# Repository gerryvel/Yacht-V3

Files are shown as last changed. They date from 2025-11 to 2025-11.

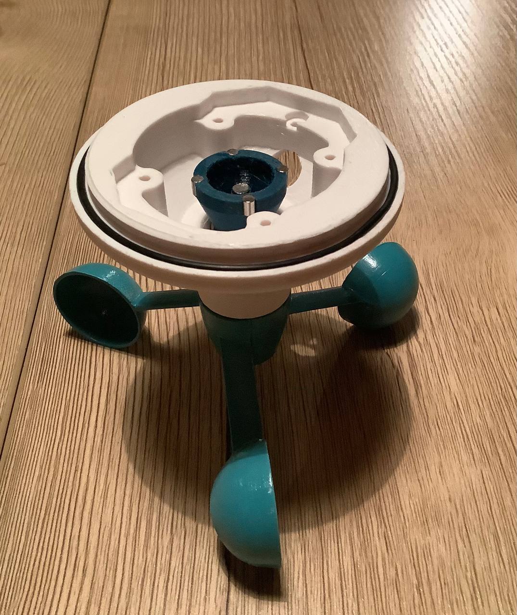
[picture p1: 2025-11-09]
Bilder/photo_2025-11-09_20-17-30.jpg

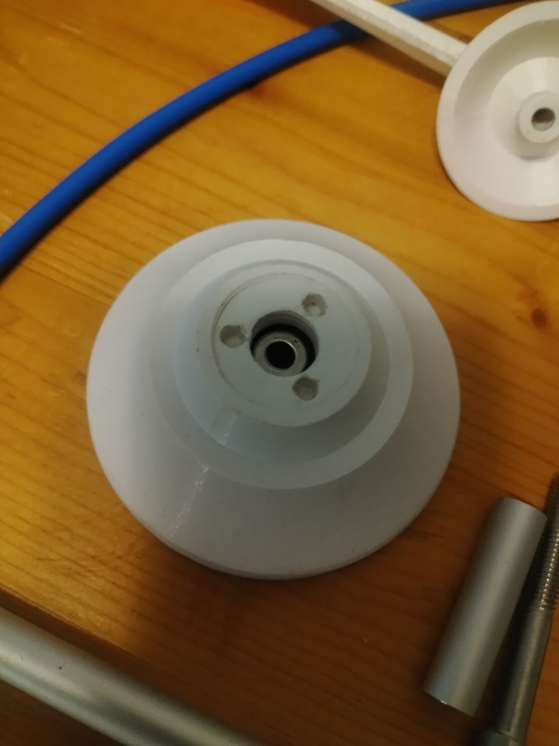
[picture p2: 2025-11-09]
Bilder/photo_2025-11-05_21-48-21.jpg

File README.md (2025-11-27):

# Yachta V3





## Description

This repository describes the installation of the "Yachta V3" wind sensor.

## Based on the work of
 
The Yachta V3 is the Windsensor "Yachta" [@norbert-walter](https://github.com/norbert-walter/Windsensor_Yachta) and the modification from a french user in the www.segeln-forum.de .
You can use the following threads (in German):
- https://www.segeln-forum.de/thread/67401-windsensor-diy/
- https://www.segeln-forum.de/thread/83726-windsensor-yachta-probleml%C3%B6sungen/

This project is part of [OpenBoatProject](https://open-boat-projects.org/)

## Sensor Modul

The PCB is the same as Yachta V2.

## Hardware




## Partlist:

### 1 Print parts
 - 1.1  Windfahne
 - 1.2  Gewindering Lager Windfahne
 - 1.3  Gehäuse-Oberteil
 - 1.4  Gehäuse-Unterteil
 - 1.5  Windlöffel 3x
 - 1.6  Löffelhalter
 - 1.7  Abstandsstück (zwischen Löffellager)
 - 1.8  Magnethalter
 - 1.9  Halterbasis
### 2 Bearings
 - 2.1  Lager 2x 625 (5x16x5 mm)
 - 2.2  Lager 1x 624 (4x13x5 mm)
### 3 Norm parts
 - 3.1  Inbus-Schraube VA 1x M3x10 (Befestigung Aluminiumrohr)
 - 3.2  Inbus-Schrauben VA 1x M5x20 (Befestigung Lager Windfahne)
 - 3.3  Inbus-Schrauben VA 1x M5x40 (Befestigung Löffellager)
 - 3.4  Inbus-Schrauben VA 1x M6x40 (Gegengewicht Windfahne)
 - 3.5  1x Mutter VA M5 (Löffellager)
 - 3.6  2x Unterlegscheibe VA  M5
### Special parts
 - 4  Aluminiumrohr 10x1mm, 200mm
 - 5  VA-Rohr 10x2, ca. 30mm (für Windspitze)
 - 6  LiYY 2x0,5 mm² oder YSLY 2x0,75 mm² ca. 300mm
 - 7  O-Ring 70x1,8 
 - 8  Leiterplatte
 - 9  Magnete (4x 1,5x5 und 1x 5x5x5)
   
## Versions

- 1.0 initial Version

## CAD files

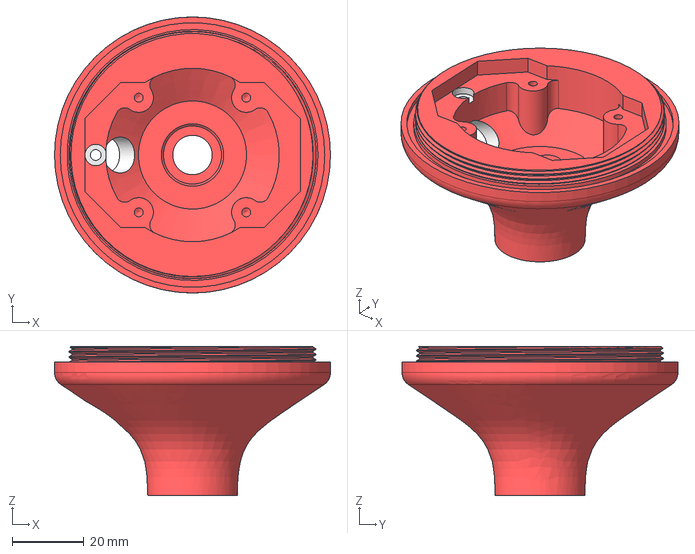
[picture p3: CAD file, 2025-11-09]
V3_Step/Yachta Unterteil-PartCut002.step
77.0 x 77.0 x 41.6 mm

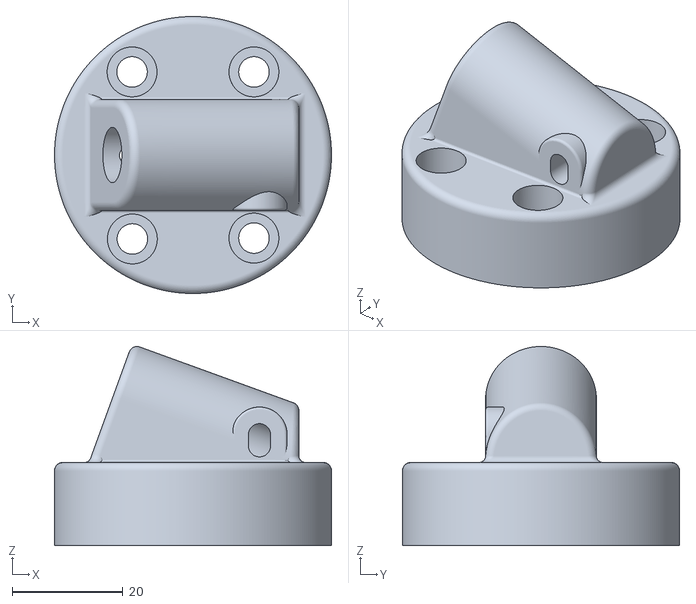
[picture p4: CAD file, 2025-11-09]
V3_Step/base_power.stl
50.0 x 50.0 x 35.9

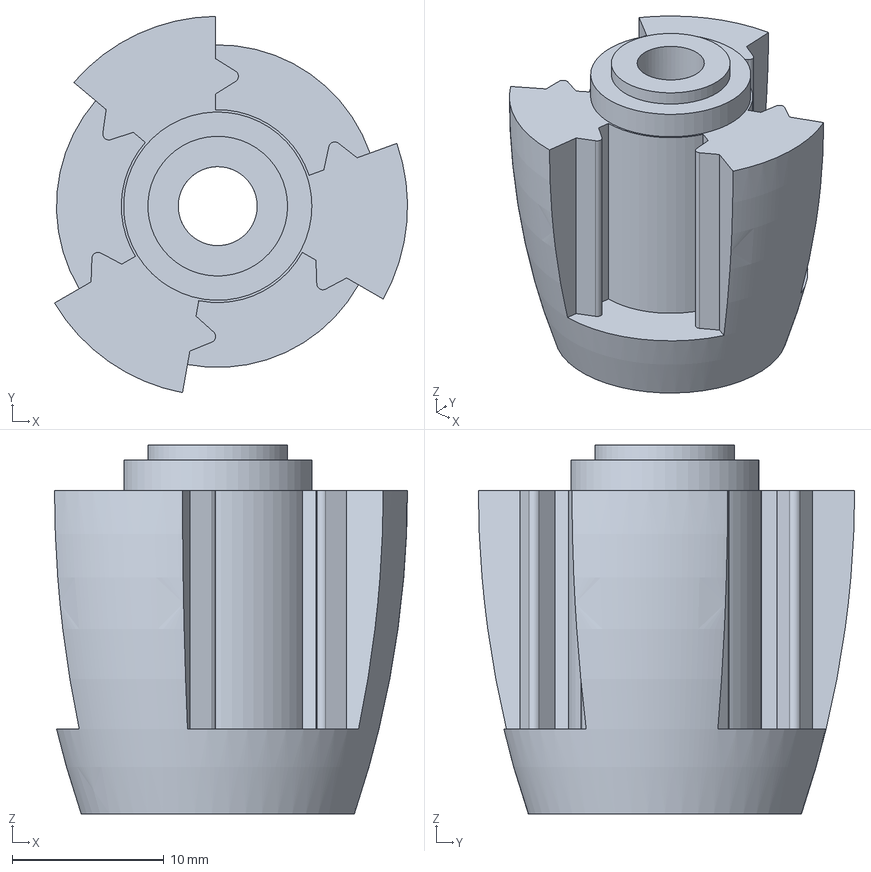
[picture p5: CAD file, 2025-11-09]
V3_Step/V1-5mm - Cup holder.step
23.2 x 24.8 x 24.3 mm

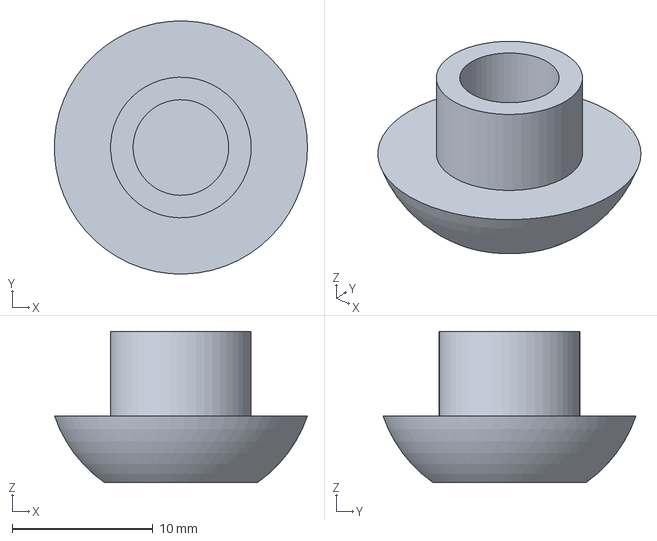
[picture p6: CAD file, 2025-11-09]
V3_Step/V1-5mm - Cap.step
18.0 x 18.0 x 10.7 mm

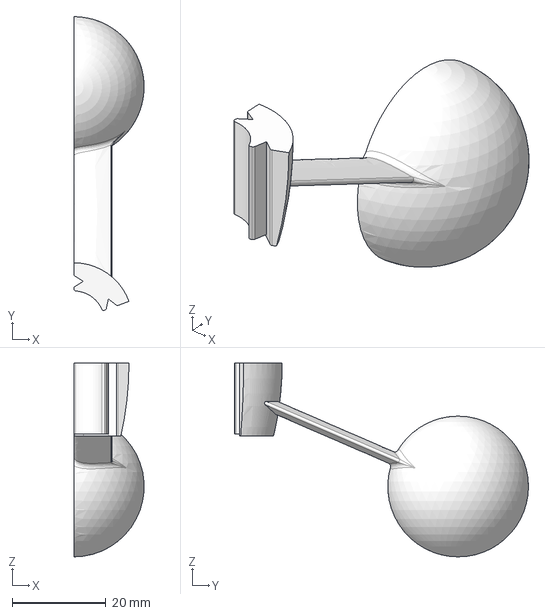
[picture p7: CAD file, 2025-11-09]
V3_Step/V1-5mm - Cup.step
15.0 x 62.7 x 41.3 mm

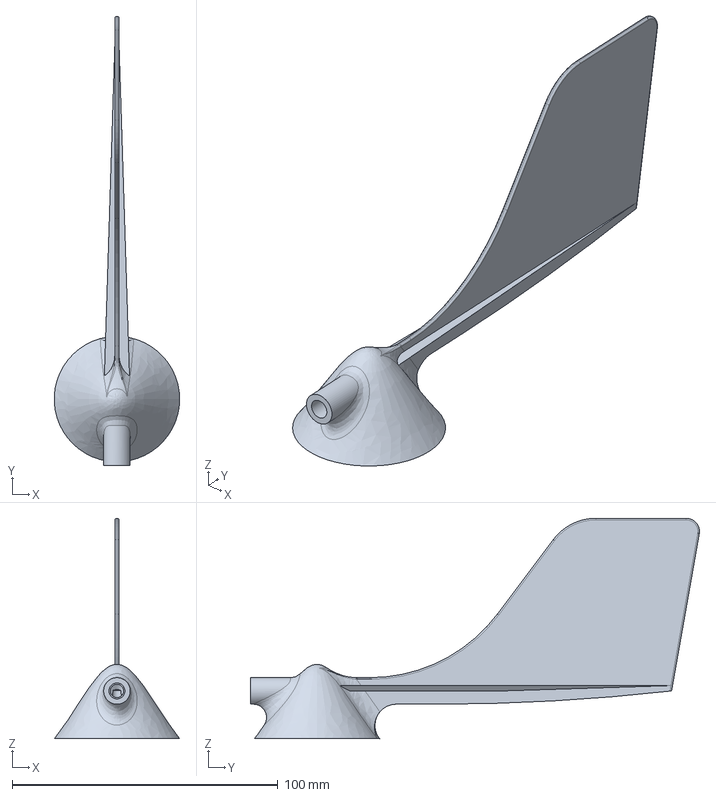
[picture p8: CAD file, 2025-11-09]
V3_Step/V1-5mm - Vane.step
47.2 x 169.0 x 83.0 mm

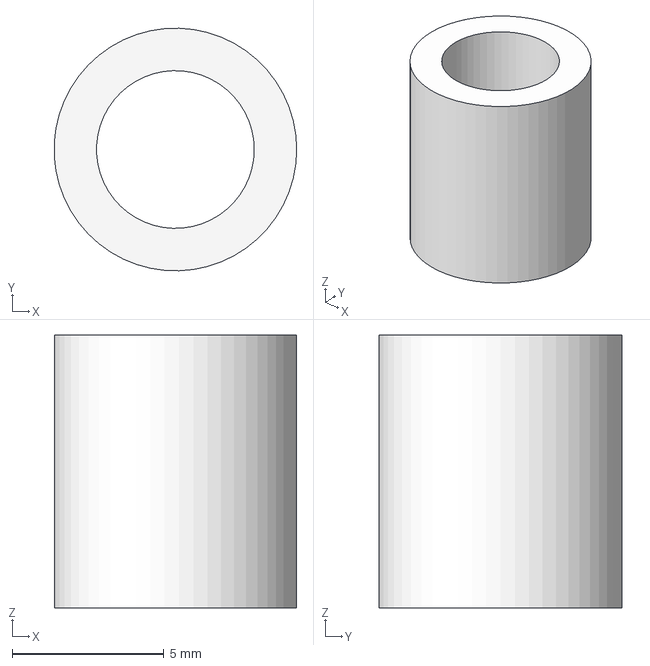
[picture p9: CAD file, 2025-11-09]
V3_Step/V1-5mm - Spacer_BB.step
7.99 x 8.00 x 9.00 mm

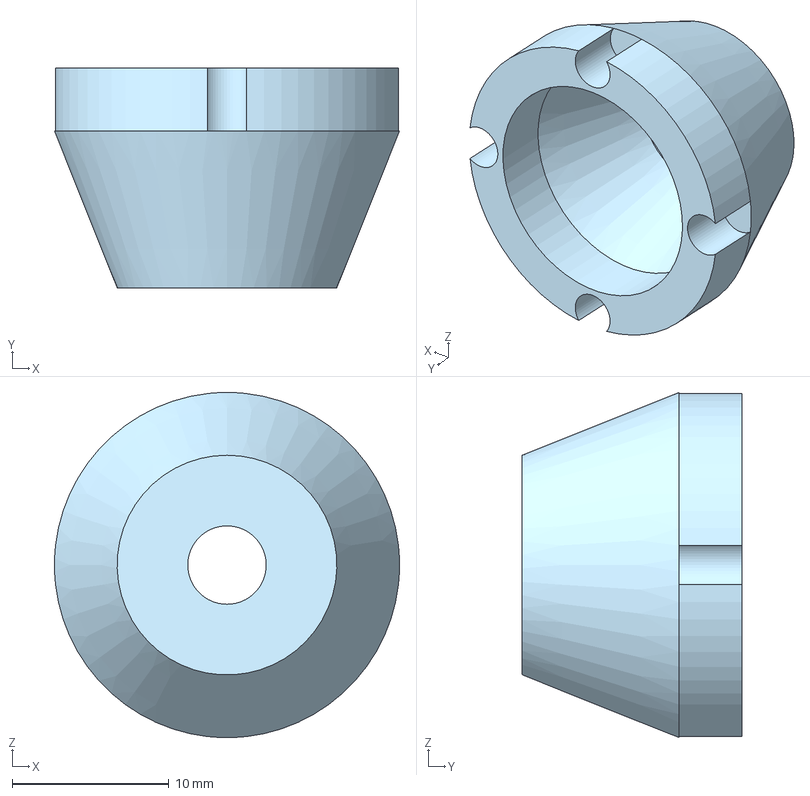
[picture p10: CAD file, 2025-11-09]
V3_Step/magnet_holder_2.step
22.0 x 14.0 x 22.0 mm

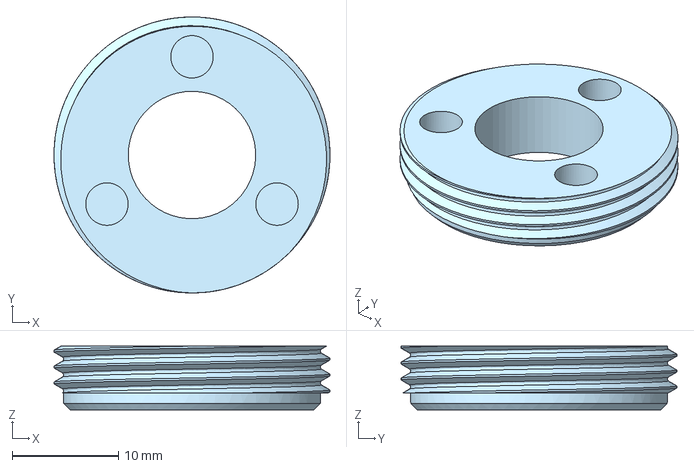
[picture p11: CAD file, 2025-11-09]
V3_Step/V1-5mm - Vane BB holder.step
26.0 x 26.0 x 6.00 mm

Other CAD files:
V3_Step/V1-5mm - Lower body.step

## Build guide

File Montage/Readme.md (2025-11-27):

# Werkzeuge

- Satz Schraubendreher
- Gewindefeile
- Lötbesteck
- Satz Inbusschlüssel
- Gewindeschneider M3, M5, M6
- Bohrersatz
- Feile, Schleifpapier

# Vorbereitungen

Aus der Stückliste sind alle Teile aus Pos. 1 gedruckt und die Außenteile lackiert. 
An dem Gehäuseober- und Unterteil muss mit der Gewindefeile (Steigung 1,5) das Gewinde ausgeräumt bzw. gesäubert werden, bis sich die beiden Teile gut zusammen- und auch wieder auseinander schrauben lassen. Vorm Lackieren zusammenschrauben, um das Gewinde sauber zu halten.

In die Windfahne wird innen zur Befestigung des Lagers im vorhandenem Loch M5 geschnitten. 
Ebenso das Gewinde zum Einsetzen des Gewichtsausgleiches mit M6 schneiden.
Die Gegengewichtsschraube am Kopf verrunden.

# Montage
## Unterteil mit Windrad
Jetzt kann man die Windlöffel [1.5] mit dem Löffelhalter [1.6] komplettieren. In den Magnethalter [1.8] die Magnete einkleben. Die Lager 1x 624 [2.2] und 1x 625 [2.1] in das Gehäuse-Unterteil einlegen, dazwischen das Abstandstück [1.7] positionieren. Die Schraube [3.3] in den Löffelhalter einführen und durch die Lager und das Abstandsstück durchfädeln, den vormontieren Magnethalter aufsetzen und mit der Mutter M5 verschrauben. Eventuell mit der Unterlegscheibe richtige Abstände einstellen, damit das Windrad frei läuft.
Aluminiumstange [4] einbauen, Loch für M3 Schraube anzeichnen. Ausbauen, bohren, Gewinde schneiden. Wieder einbauen und mit der Schraube M3x10 sichern. Kabel [6] einfädeln, Mantel absetzen und Adern abisolieren.
Leiterplatte einlegen und prüfen, ob der Abstand zu den Magneten passt, eventuell anpassen. Mit Schraubensicherungslack sichern.

## Oberteil mit Windfahne

Im Gehäuse-Oberteil das Lager 625 einlegen und mit dem Gewindering [1.2] festschrauben. Mit der Schraube M5x20 [3.3] die Windfahne befestigen. Jetzt die Gegengewichtsschraube mit dem VA-Rohr 10x2x30 [5] (genaue Länge durch ausbalancieren bestimmen) komplettieren, eindrehen und ausbalancieren. Eventuell mit einer Unterlegscheibe M5 den Abstand der Fahne zum Gehäuse-Oberteil einstellen. Schraube mit Lack sichern. Den Magneten 5x5x5 an den Schraubenkopf festkleben.

# Komplettieren

Kabeladern an der Leiterplatte durchfädeln, Freilauf des Magnethalters beachten. Adern anlöten. O-Ring [7] einlegen und beide Schalen zusammenschrauben. Windfahne und Windrad bewegen und prüfen, ob die Magneten frei laufen und nicht an der Leiterplatte anschlagen. Halterbasis an der anderen Seite des Aluminiumrohrs anbauen und Kabel durchfädeln.

# Inbetriebnahme 

Die weitere Inbetriebnahme nach dem Handbuch des Yachta V2 vornehmen.

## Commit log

2025-11-09 Update README with Yachta V3 details and part list
    Added detailed information about the Yachta V3 wind sensor, including hardware specifications and part list with links.
2025-11-09 Update link to Yachta wind sensor repository
2025-11-09 Revise part list and hardware details in README
    Updated part list and added details for screws and bearings.
2025-11-09 Revise description of Yachta V3 wind sensor
2025-11-09 Update Readme with tools and assembly instructions
    Added detailed assembly instructions and tool list for the project.
2025-11-09 Fix formatting and clarify assembly instructions
2025-11-27 Enhance Readme with component references
    Updated assembly instructions with reference numbers for components.
